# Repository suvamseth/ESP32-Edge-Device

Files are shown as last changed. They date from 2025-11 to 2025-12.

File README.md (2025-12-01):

<div align="center">

# Industrial IoT Smart Edge Device 

**A robust, hybrid sensing Smart Edge Device designed for  home energy monitoring, industrial-grade energy monitoring and protection. Features dual-protocol communication (MQTT & Modbus).**




</div>

## 📖 Overview
This Smart Edge Node (SED) functions as a comprehensive data acquisition and protection unit for household and industrial loads. Unlike standard smart plugs, this device integrates **hybrid sensing** architecture: it uses a **PZEM-004T** for precision metering and features **AMC1200 Isolation Amplifier** used for galvanic isolation and transient analysis, it also executes the on/off command of load using relay.

The system is engineered to prioritize reliability in noisy electrical environments by utilizing **W5500 Ethernet** for hardwired communication, supporting both **MQTT** for cloud-server dashboards (Node-RED) and **Modbus TCP** for legacy industrial integration.

---

## 📸 Visuals
| **3D PCB Render** | **Real Device** |
|:---:|:---:|
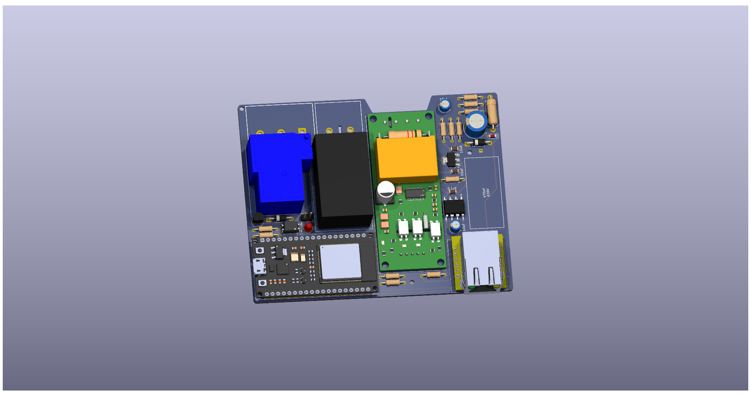
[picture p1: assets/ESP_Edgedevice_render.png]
3D Render
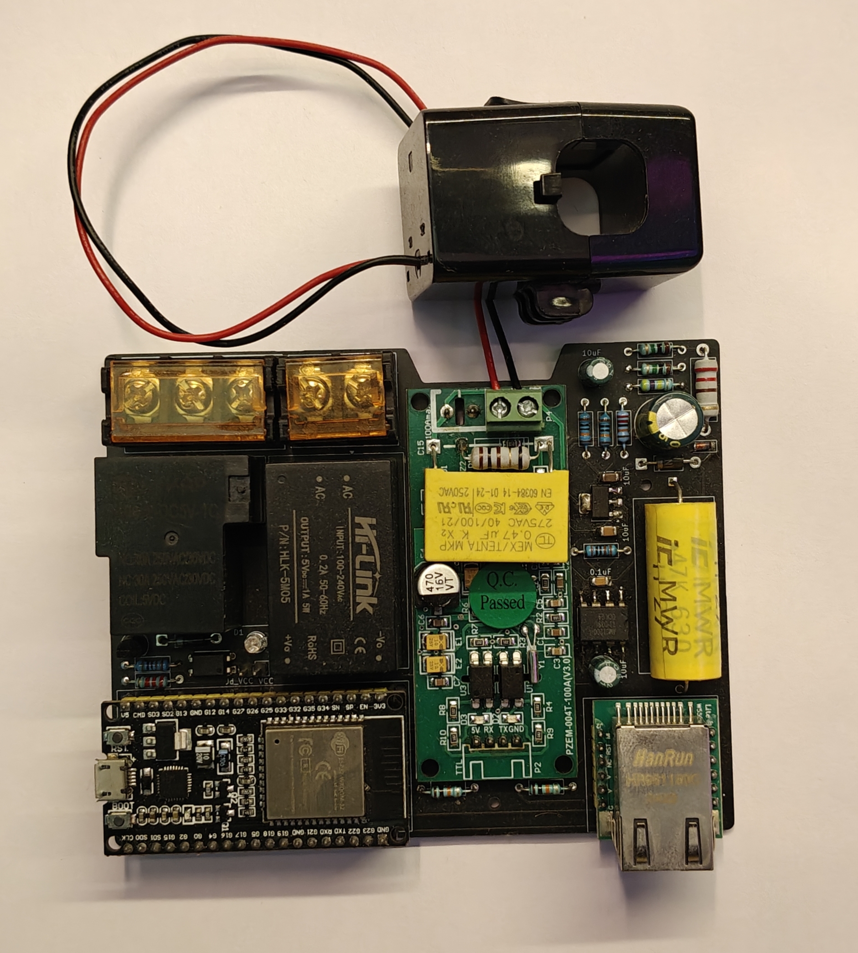
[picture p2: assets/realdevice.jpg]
Real Device
|  |  |
| *Final PCB Design (KiCad)* | *Final PCB from the fabricator* |

---

## ⚡ Key Features

### 1. Hybrid Sensing Architecture
* **Precision Metering (PZEM-004T):**
    * Accurate calculation of RMS Voltage, Current, Active Power, Energy (kWh), Frequency, and Power Factor.
    * Sends this data to esp32 using UART protocol.
* **Transient Protection (AMC1200):**
    * Provides **4250V peak galvanic isolation**.
    * Feeds a high-speed analog signal to the ESP32 to detect **Voltage Surges and Dips** in real-time (sub-cycle detection), triggering safety cutoffs faster than digital sensors allow.

### 2. Industrial Connectivity
* **Ethernet (W5500):** Uses SPI interface for stable, low-latency connection, eliminating Wi-Fi instability in industrial settings.
* **Dual-Protocol Stack:**
    * **MQTT:** Publishes telemetry to a local broker for visualization on Node-RED.
    * **Modbus TCP:** Acts as a slave device, allowing PLCs or SCADA systems to poll data.

### 3. Load Control & Safety
* **30A Relay Integration:** Allows remote ON/OFF control via dashboard or automated safety disconnection during surge events.
* **Isolated Logic:** Low-voltage logic (ESP32) is completely isolated from High-Voltage mains via the AMC1200 and PC817 Optocouplers.

---
## 📊 Dashboard View
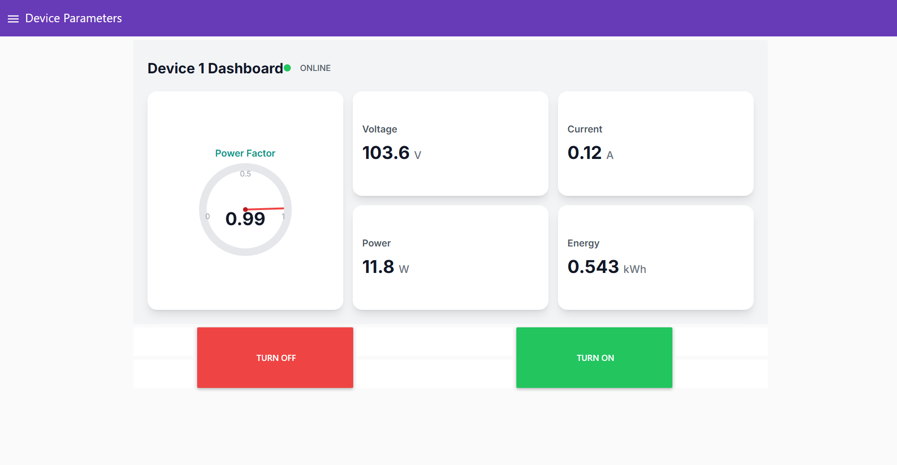
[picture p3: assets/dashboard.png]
Node-RED Application
**
*Real-time monitoring interface showing energy consumption metrics and relay status.*

---
## 👨‍💻 Author
**Suvam Seth**
*Power Engineering Student | PCB Design | IoT Systems*

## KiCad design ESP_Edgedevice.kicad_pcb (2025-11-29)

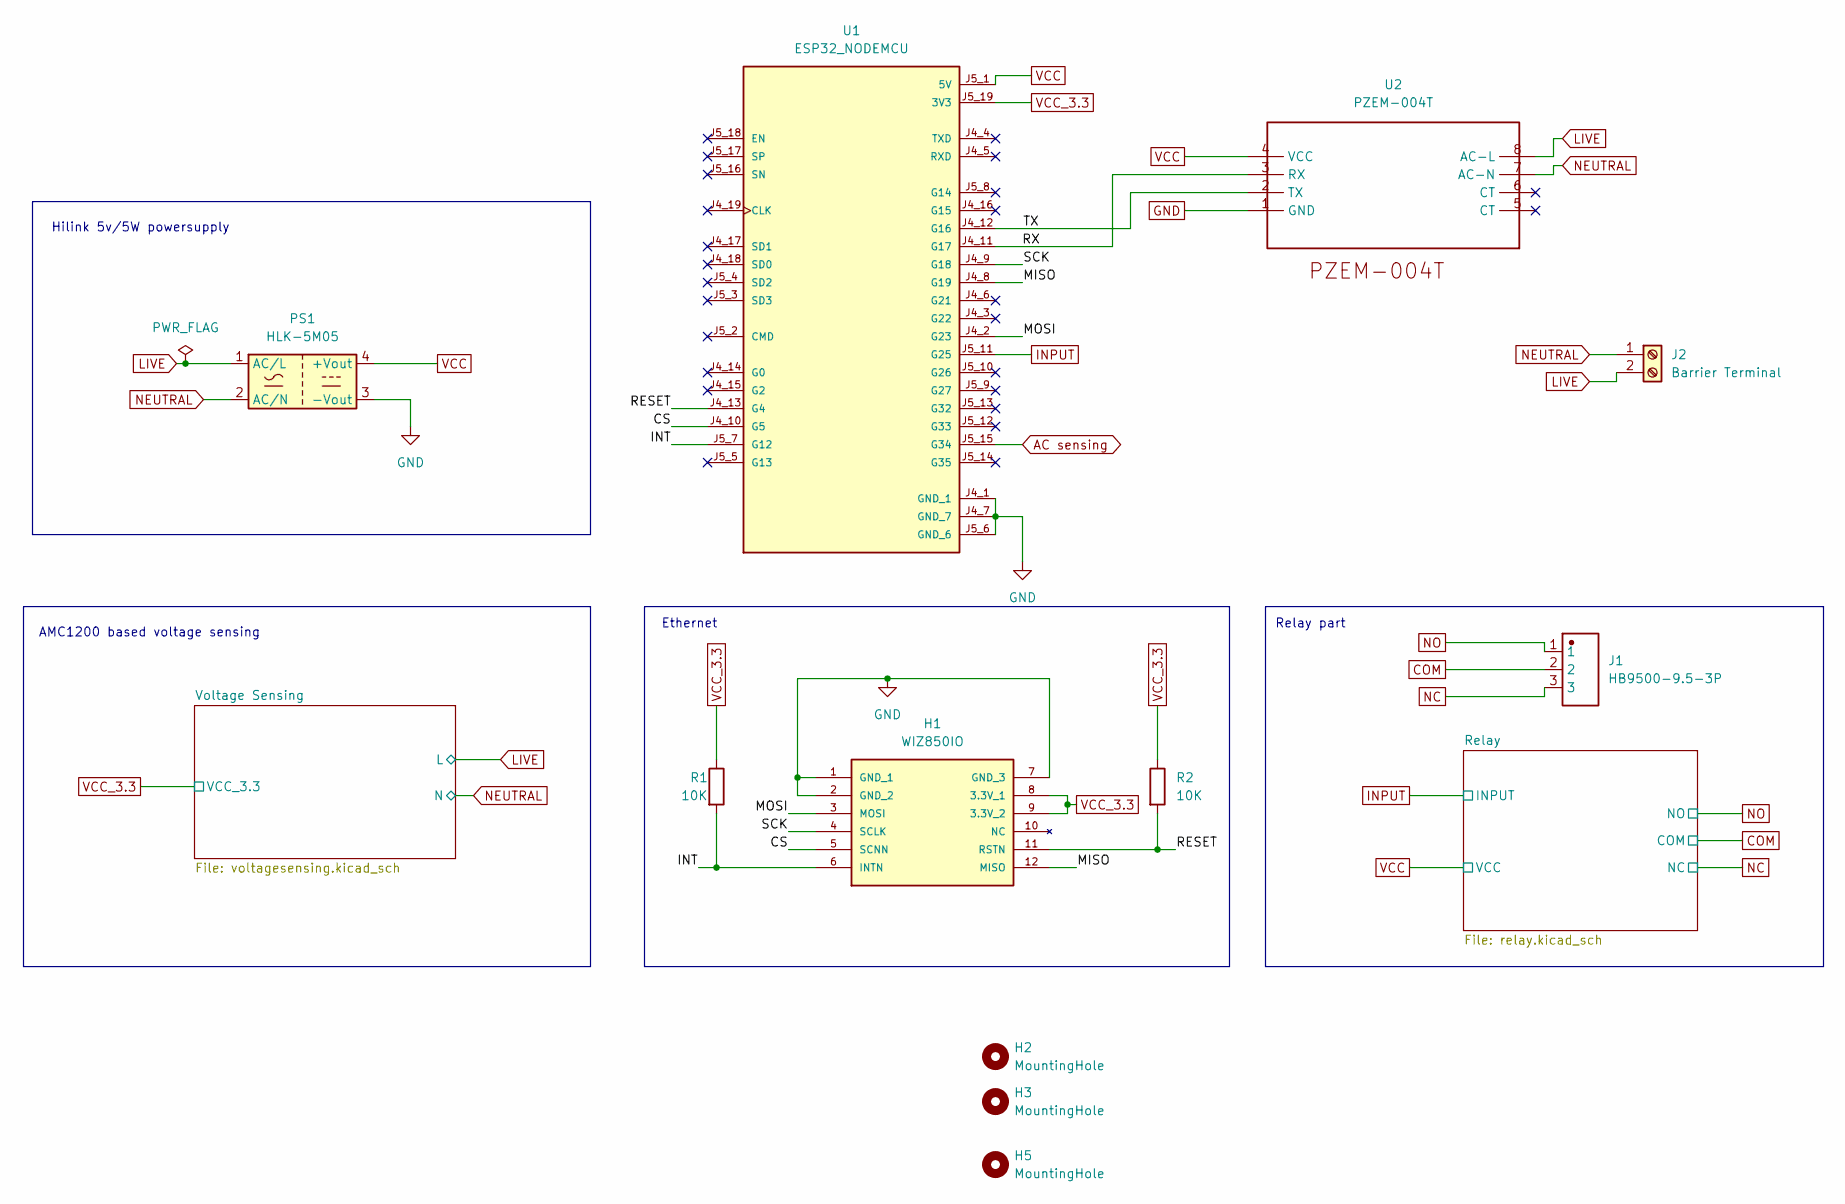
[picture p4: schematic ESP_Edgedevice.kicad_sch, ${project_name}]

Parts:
H1: WIZ850IO; MANUFACTURER_PART_NUMBER WIZ850IO
H2, H3, H5: MountingHole; MountingHole_2.1mm
J1: HB9500-9.5-3P; CONN-TH_HB9500-9.5-3P; Manufacturer Part HB9500-9.5-3P
J2: Barrier Terminal; Terminal_Block_9.5mm-2
PS1: HLK-5M05; Converter_ACDC_Hi-Link_HLK-5Mxx
R1, R2: 10K; R_Axial_DIN0207_L6.3mm_D2.5mm_P10.16mm_Horizontal
U1: ESP32_NODEMCU; MODULE_ESP32_NODEMCU
U2: PZEM-004T; PZEM-004T V3

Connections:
/CS: H1.5 (SCNN), U1.J4_10 (G5)
/INT: H1.6 (INTN), R1.2, U1.J5_7 (G12)
/MISO: H1.12 (MISO), U1.J4_8 (G19)
/MOSI: H1.3 (MOSI), U1.J4_2 (G23)
/RESET: H1.11 (RSTN), R2.2, U1.J4_13 (G4)
/RX: U1.J4_11 (G17), U2.3 (RX)
/SCK: H1.4 (SCLK), U1.J4_9 (G18)
/TX: U1.J4_12 (G16), U2.2 (TX)
AC sensing: U1.J5_15 (G34); also elsewhere on the board
COM: J1.2; also elsewhere on the board
GND: H1.1 (GND_1), H1.2 (GND_2), H1.7 (GND_3), PS1.3 (-Vout), U1.J4_1 (GND_1), U1.J4_7 (GND_7), U1.J5_6 (GND_6), U2.1 (GND); also elsewhere on the board
INPUT: U1.J5_11 (G25); also elsewhere on the board
LIVE: J2.2, PS1.1 (AC/L), U2.8 (AC-L); also elsewhere on the board
NC: J1.3; also elsewhere on the board
NEUTRAL: J2.1, PS1.2 (AC/N), U2.7 (AC-N); also elsewhere on the board
NO: J1.1; also elsewhere on the board
VCC: PS1.4 (+Vout), U1.J5_1 (5V), U2.4 (VCC); also elsewhere on the board
VCC_3.3: H1.8 (3.3V_1), H1.9 (3.3V_2), R1.1, R2.1, U1.J5_19 (3V3); also elsewhere on the board

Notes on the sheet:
Relay part
AMC1200 based voltage sensing
Hilink 5v/5W powersupply
Ethernet

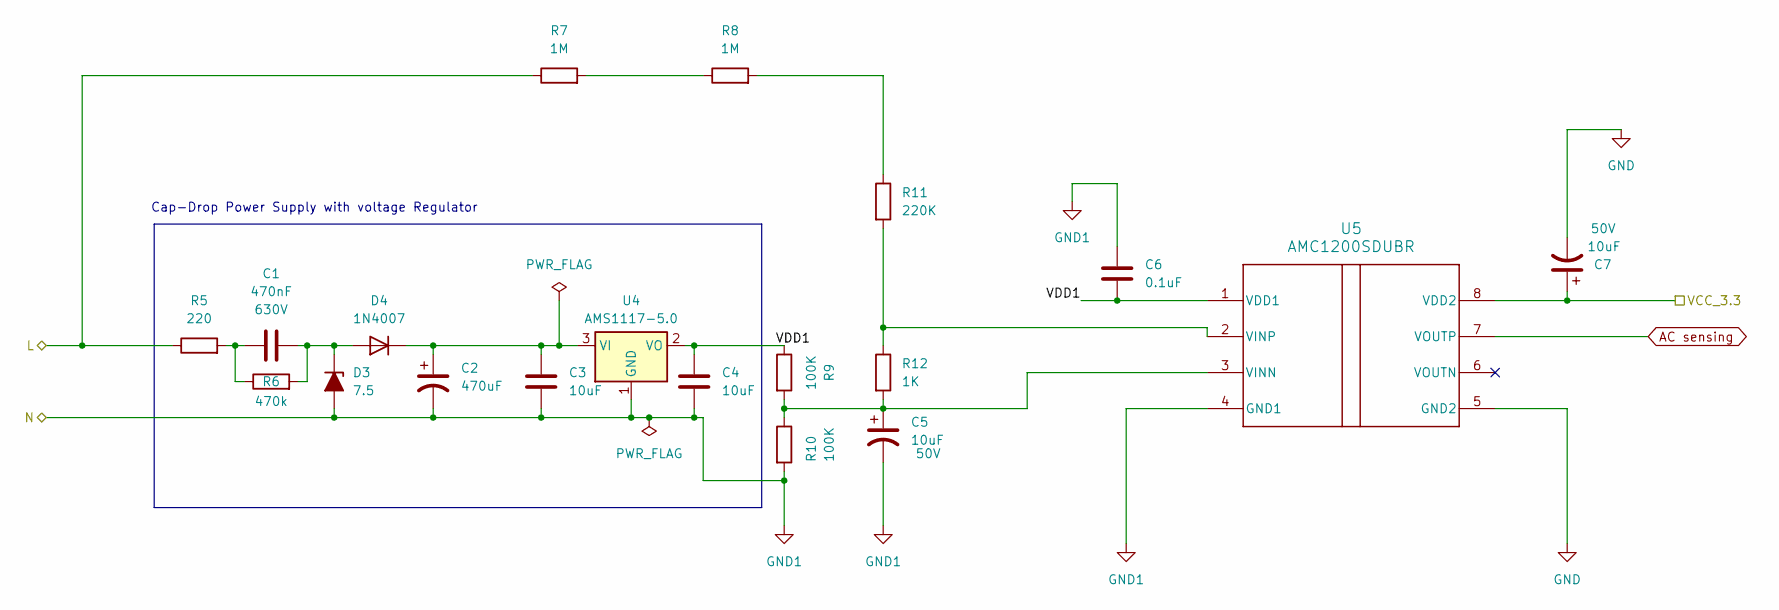
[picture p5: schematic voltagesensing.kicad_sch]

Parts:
C1: 470nF; CAP_150AXIAL_RF_CND; voltage 630V
C2: 470uF; CP_Radial_D10.0mm_P5.00mm
C3, C4: 10uF; C_1206_3216Metric_Pad1.33x1.80mm_HandSolder
C5, C7: 10uF; CP_Radial_D5.0mm_P2.50mm; Voltage 50V
C6: 0.1uF; C_1206_3216Metric
D3: 7.5; D_MiniMELF
D4: 1N4007; D_DO-41_SOD81_P10.16mm_Horizontal
R5: 220; R_Axial_DIN0414_L11.9mm_D4.5mm_P15.24mm_Horizontal
R6: 470k; R_Axial_DIN0207_L6.3mm_D2.5mm_P10.16mm_Horizontal
R7, R8: 1M; R_Axial_DIN0207_L6.3mm_D2.5mm_P10.16mm_Horizontal
R9, R10: 100K; R_Axial_DIN0207_L6.3mm_D2.5mm_P10.16mm_Horizontal
R11: 220K; R_Axial_DIN0207_L6.3mm_D2.5mm_P10.16mm_Horizontal
R12: 1K; R_Axial_DIN0207_L6.3mm_D2.5mm_P10.16mm_Horizontal
U4: AMS1117-5.0; SOT-223-3_TabPin2
U5: AMC1200SDUBR; DUB0008A-IPC_A

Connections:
/Voltage Sensing/VDD1: C4.1, C6.2, R9.1, U4.2 (VO), U5.1 (VDD1)
AC sensing: U5.7 (VOUTP); also elsewhere on the board
GND: C7.2, U5.5 (GND2); also elsewhere on the board
LIVE: R5.1, R7.1; also elsewhere on the board
NEUTRAL: C2.2, C3.2, C4.2, C5.2, C6.1, D3.2 (A), R10.2, U4.1 (GND), U5.4 (GND1); also elsewhere on the board
unnamed: C1.1, R5.2, R6.1
unnamed: C1.2, D3.1 (K), D4.2 (A), R6.2
unnamed: C2.1, C3.1, D4.1 (K), U4.3 (VI)
unnamed: R7.2, R8.1
unnamed: R8.2, R11.1
unnamed: C5.1, R9.2, R10.1, R12.2, U5.3 (VINN)
unnamed: R11.2, R12.1, U5.2 (VINP)
VCC_3.3: C7.1, U5.8 (VDD2); also elsewhere on the board

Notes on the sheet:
Cap-Drop Power Supply with voltage Regulator

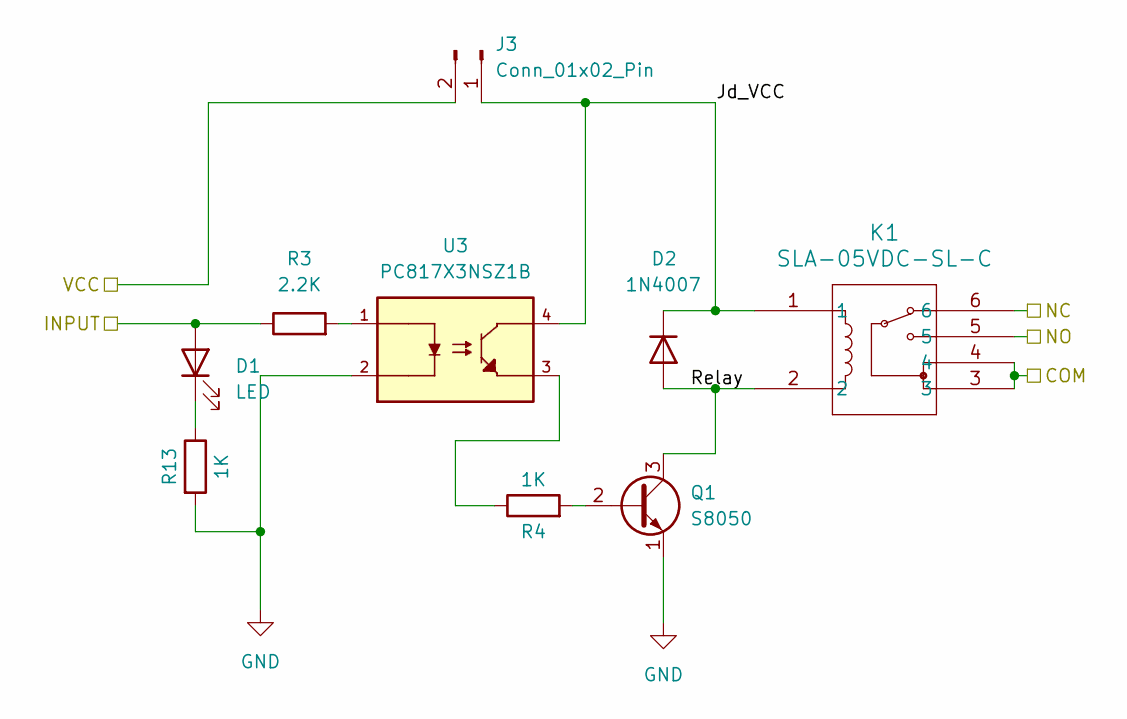
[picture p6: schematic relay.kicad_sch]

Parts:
D1: LED; LED_D3.0mm
D2: 1N4007; D_DO-41_SOD81_P10.16mm_Horizontal
J3: Conn_01x02_Pin; PinHeader_1x02_P2.54mm_Vertical
K1: SLA-05VDC-SL-C; K_SLA_C_NFR
Q1: S8050; TO-92_Inline
R3: 2.2K; R_Axial_DIN0207_L6.3mm_D2.5mm_P10.16mm_Horizontal
R4, R13: 1K; R_Axial_DIN0207_L6.3mm_D2.5mm_P10.16mm_Horizontal
U3: PC817X3NSZ1B; DIP762W50P254L495H455Q4; PARTREV October 7, 2016

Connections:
/Relay/Jd_VCC: D2.1 (K), J3.1, K1.1, U3.4
/Relay/Relay: D2.2 (A), K1.2, Q1.3 (C)
COM: K1.3, K1.4; also elsewhere on the board
GND: Q1.1 (E), R13.2, U3.2; also elsewhere on the board
INPUT: D1.2 (A), R3.1; also elsewhere on the board
NC: K1.6; also elsewhere on the board
NO: K1.5; also elsewhere on the board
unnamed: D1.1 (K), R13.1
unnamed: Q1.2 (B), R4.2
unnamed: R3.2, U3.1
unnamed: R4.1, U3.3
VCC: J3.2; also elsewhere on the board

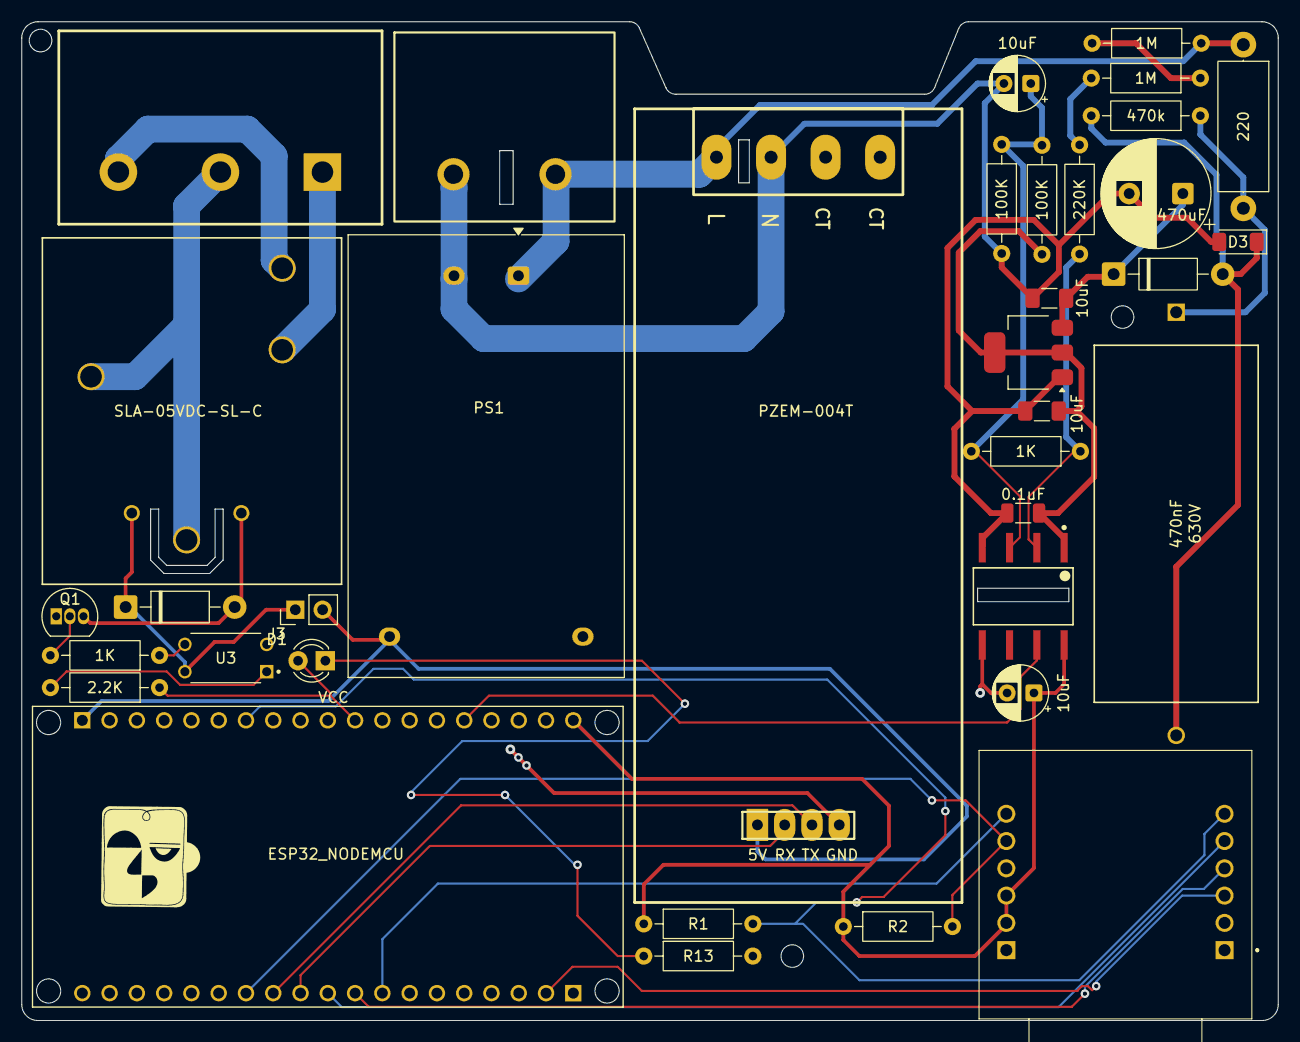
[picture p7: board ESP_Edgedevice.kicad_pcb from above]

Board: 2 copper layers, 117.0 x 93.0 mm, 39 parts (0 on the bottom side), 32 nets.

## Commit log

2025-08-04 Schematic Of Relay Portion Completed
    [ESP_Edgedevice.kicad_sch, relay.kicad_sch]
2025-08-04 30Amp Relay Schematic Completed
    [ESP_Edgedevice.kicad_sch, relay.kicad_sch]
2025-08-05 minor changes
    [ESP_Edgedevice.kicad_sch, relay.kicad_sch]
2025-08-07 Schematic Editing Done
    [ESP_Edgedevice.kicad_sch, relay.kicad_sch, voltagesensing.kicad_sch]
2025-08-07 Assignment Of Footprint Done
    [ESP_Edgedevice.kicad_sch, relay.kicad_sch, voltagesensing.kicad_sch]
2025-08-09 Placement Of Component on PCB Done
    [ESP_Edgedevice.kicad_pcb, ESP_Edgedevice.kicad_sch, relay.kicad_sch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]
2025-08-10 PCB Routing Completed
    [ESP_Edgedevice.kicad_pcb, ESP_Edgedevice.kicad_sch, relay.kicad_sch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]
2025-08-15 FINAL COMMIT
    [ESP_Edgedevice.kicad_pcb, voltagesensing.kicad_sch]
2025-11-29 Fix: Corrected Schematic and Updated PCB Layout
    [ESP_Edgedevice.kicad_pcb, relay.kicad_sch]
